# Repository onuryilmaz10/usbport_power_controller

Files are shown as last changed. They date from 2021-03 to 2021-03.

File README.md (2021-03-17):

# usbport_power_controller
An arduino based product UPC allows you to manage the connection of your computer between usb powered device. You can control it remotely with serial communication software running on your system. 
Designed by Onur Yilmaz and Yusuf Arabaci. 

Contact mail: onr.yilmaz10@gmail.com

# Connection 
Detect CH340 in ComPorts list.
Baud Rate is 9600. After serial communication setup, connects if you send "C" (connect), disconnects if you send "D" (disconnect).

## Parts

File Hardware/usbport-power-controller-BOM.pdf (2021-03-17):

Qty | Designation | Package | Designator
6 | 22pF | C1206 | C1,C2,C11,C12,C18,C19
7 | 100nF | C1206 | C3,C5,C6,C13,C15,C16,C17
3 | 10uF | C1206 | C4,C7,C9
3 | 100uF | C1206 | C8,C10,C20
1 | 40V/1A Diode | DO214AC(SMA) | D1
1 | Green Red | LED-1206 | D2
1 | Connector USB B 90C | Female | J1
1 | Power Jack | 2.1x5x5mm | J2
1 | Connector USB 2.0 A H | Female | J3
1 | Pin Header | 6x1 | J4
1 | Pin Header(Power Jumper) | 2x1 | J5
1 | TX2-5V Relay | THT DPDT 2FORMC | K1
1 | BC817 | SOT23-BEC | Q1
2 | 12.000MHz Crystal | HC-49UP | Y1,Y2
1 | 16.000MHz Crystal | HC-49UP | Y3
1 | 2.7k Ohm | R1206 | R1
3 | 100k Ohm | R1206 | R2,R3,R5
1 | 47k Ohm | R1206 | R4
1 | 330 Ohm | R1206 | R6
1 | Fe1.1S 4P Hub Controller 2.0 | SSOP28 | U1
1 | CH340G | SOIC16 | U2
1 | IC MCU 8BIT 32KB FLASH | TQFP-32 | Atmega328P-AU

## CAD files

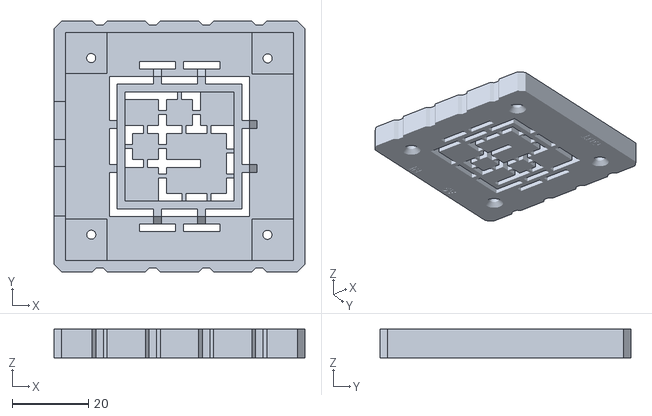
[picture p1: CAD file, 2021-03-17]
3dPrint/cap.stl
66.0 x 66.0 x 7.50

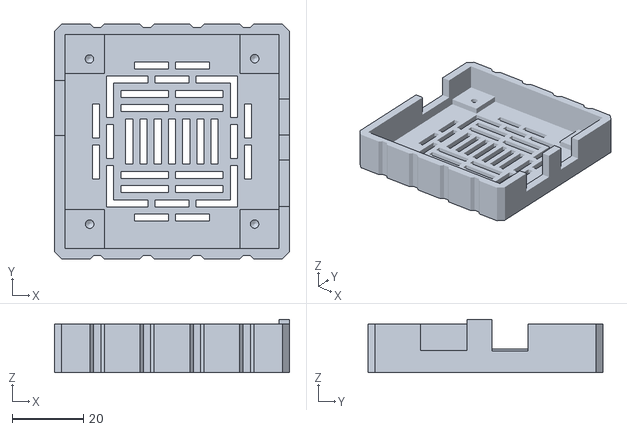
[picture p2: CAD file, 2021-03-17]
3dPrint/box.stl
66.0 x 66.0 x 15.0

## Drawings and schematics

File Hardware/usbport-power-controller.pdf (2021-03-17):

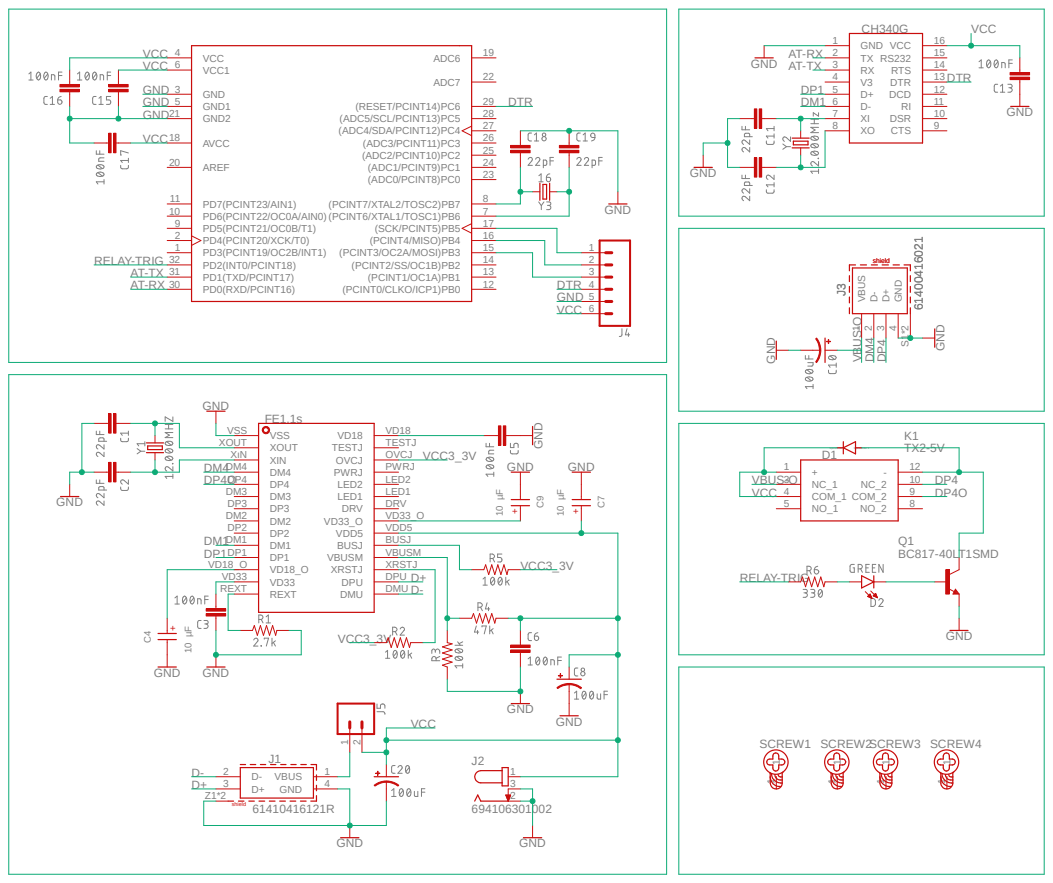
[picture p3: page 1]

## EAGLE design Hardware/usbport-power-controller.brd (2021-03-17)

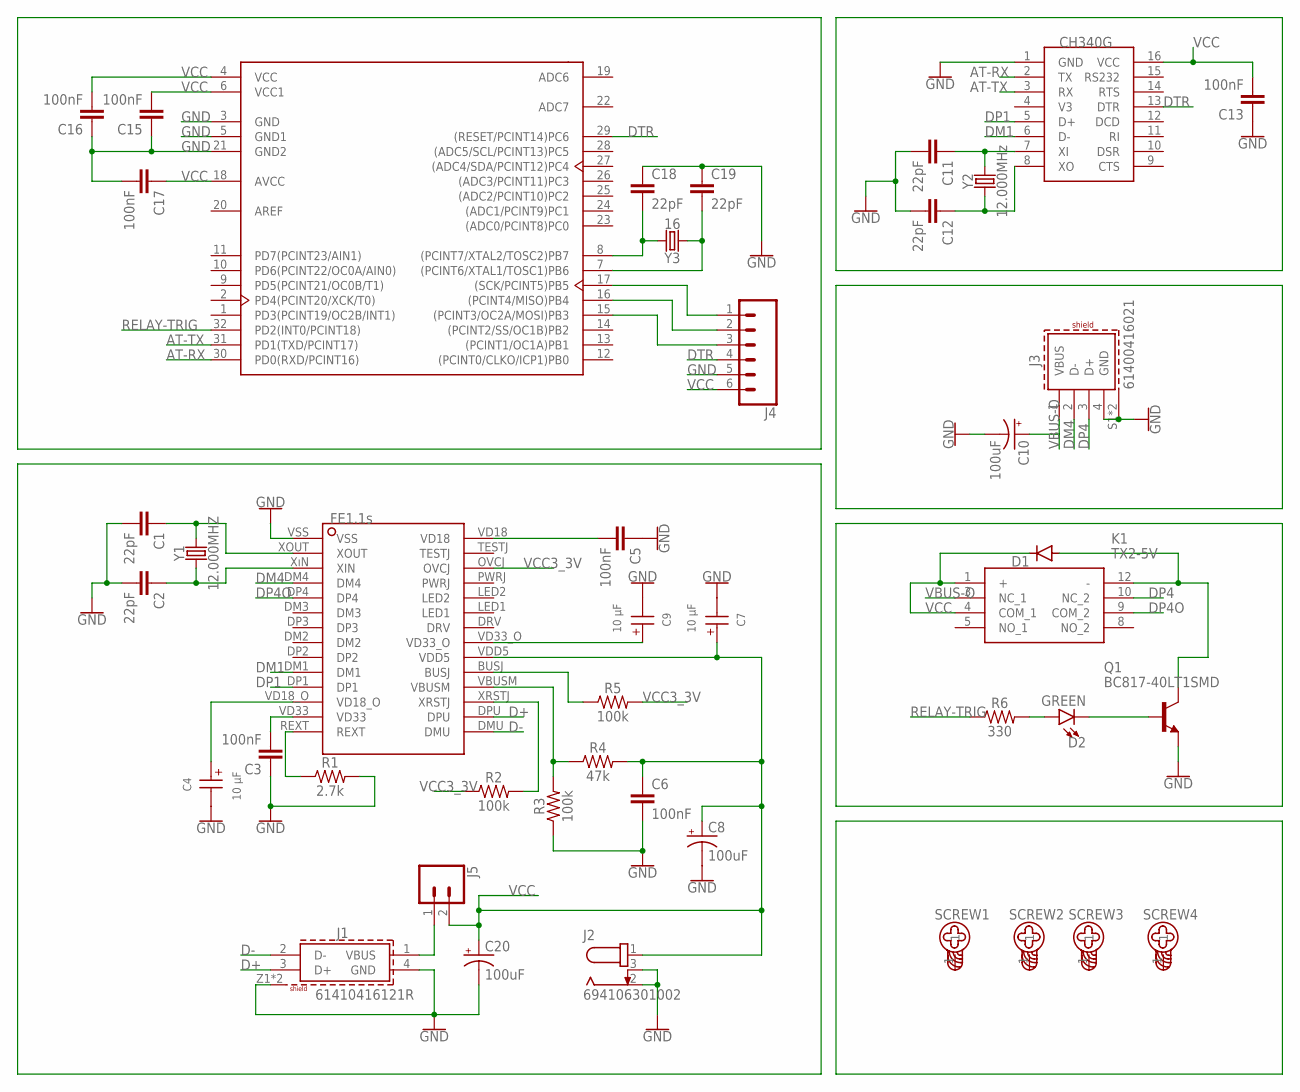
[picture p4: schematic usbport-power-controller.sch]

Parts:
ATMEGA328P-AU: ATMEGA328P-AU; TQFP-32
C1, C2, C11, C12, C18, C19: 22pF; 1206
C3, C5, C6, C13, C15, C16, C17: 100nF; 1206
C4, C7, C9: 10 µF; WCAP-ASLI_4X5.5(DXL)
C8, C10, C20: 100uF; PANASONIC_D
D1: DIODE-DO-214AC; DO-214AC
D2: GREEN; LED-1206
J1: 61410416121R
J2: 694106301002
J3: 61400416021
J4: CONN_06NO_SILK_FEMALE_PTH; 1X06_NO_SILK
J5: CONN_02; 1X02
K1: TX2-5V; TX2-24V
Q1: BC817-40LT1SMD; SOT23-BEC
R1: 2.7k; 1206
R2, R3, R5: 100k; 1206
R4: 47k; 1206
R6: 330; 1206
SCREW1, SCREW2, SCREW3, SCREW4: 4946
U$1: FE1.1S
U$2: CH340G; SOIC16
Y1: 12.000MHZ; HC49UP
Y2: 12.000MHz; HC49UP
Y3: 16; HC49UP

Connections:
AREF: ATMEGA328P-AU.20 (AREF)
AT-RX: ATMEGA328P-AU.30 (PD0(RXD/PCINT16)), U$2.2 (TX)
AT-TX: ATMEGA328P-AU.31 (PD1(TXD/PCINT17)), U$2.3 (RX)
D+: J1.3 (D+), U$1.DPU
D-: J1.2 (D-), U$1.DMU
DM1: U$1.DM1, U$2.6 (D-)
DM4: J3.2 (D-), U$1.DM4
DP1: U$1.DP1, U$2.5 (D+)
DP4: J3.3 (D+), K1.10 (NC_2)
DP4O: K1.9 (COM_2), U$1.DP4
DTR: ATMEGA328P-AU.29 ((RESET/PCINT14)PC6), J4.4, U$2.13 (DTR)
GND: ATMEGA328P-AU.3 (GND), ATMEGA328P-AU.5 (GND1), ATMEGA328P-AU.21 (GND2), C1.2, C2.2, C3.1, C4.2 (-), C5.1, C6.2, C7.2 (-), C8.-, C9.2 (-), C10.-, C11.2, C12.2, C13.1, C15.1, C16.1, C17.2, C18.1, C19.1, C20.-, J1.4 (GND), J1.Z1 (SHIELD), J1.Z2 (SHIELD), J2.2, J2.3, J3.4 (GND), J3.S1 (SHIELD), J3.S2 (SHIELD), J4.5, Q1.E, R1.2, R3.1, U$1.VSS, U$2.1 (GND)
unnamed: C2.1, U$1.XıN (XIN), Y1.1
unnamed: R2.2, U$1.XRSTJ
unnamed: R3.2, R4.1, U$1.VBUSM
unnamed: R1.1, U$1.REXT
unnamed: C1.1, U$1.XOUT, Y1.2
unnamed: C3.2, U$1.VD33
unnamed: R5.1, U$1.BUSJ
unnamed: D1.A, K1.12 (-), Q1.C
unnamed: C12.1, U$2.8 (XO), Y2.1
unnamed: C4.1 (+), U$1.VD18_O
unnamed: C11.1, U$2.7 (XI), Y2.2
unnamed: D2.C, Q1.B
unnamed: D2.A, R6.2
unnamed: ATMEGA328P-AU.8 ((PCINT7/XTAL2/TOSC2)PB7), C18.2, Y3.2
unnamed: ATMEGA328P-AU.17 ((SCK/PCINT5)PB5), J4.1
unnamed: ATMEGA328P-AU.7 ((PCINT6/XTAL1/TOSC1)PB6), C19.2, Y3.1
unnamed: ATMEGA328P-AU.16 ((PCINT4/MISO)PB4), J4.2
unnamed: ATMEGA328P-AU.15 ((PCINT3/OC2A/MOSI)PB3), J4.3
unnamed: J1.1 (VBUS), J5.1
unnamed: C5.2, U$1.VD18
RELAY-TRIG: ATMEGA328P-AU.32 (PD2(INT0/PCINT18)), R6.1
VBUS-O: C10.+, J3.1 (VBUS), K1.3 (NC_1)
VCC: ATMEGA328P-AU.4 (VCC), ATMEGA328P-AU.6 (VCC1), ATMEGA328P-AU.18 (AVCC), C6.1, C7.1 (+), C8.+, C13.2, C15.2, C16.2, C17.1, C20.+, D1.C, J2.1, J4.6, J5.2, K1.1 (+), K1.4 (COM_1), R4.2, U$1.VDD5, U$2.16 (VCC)
VCC3_3V: C9.1 (+), R2.1, R5.2, U$1.OVCJ, U$1.VD33_O

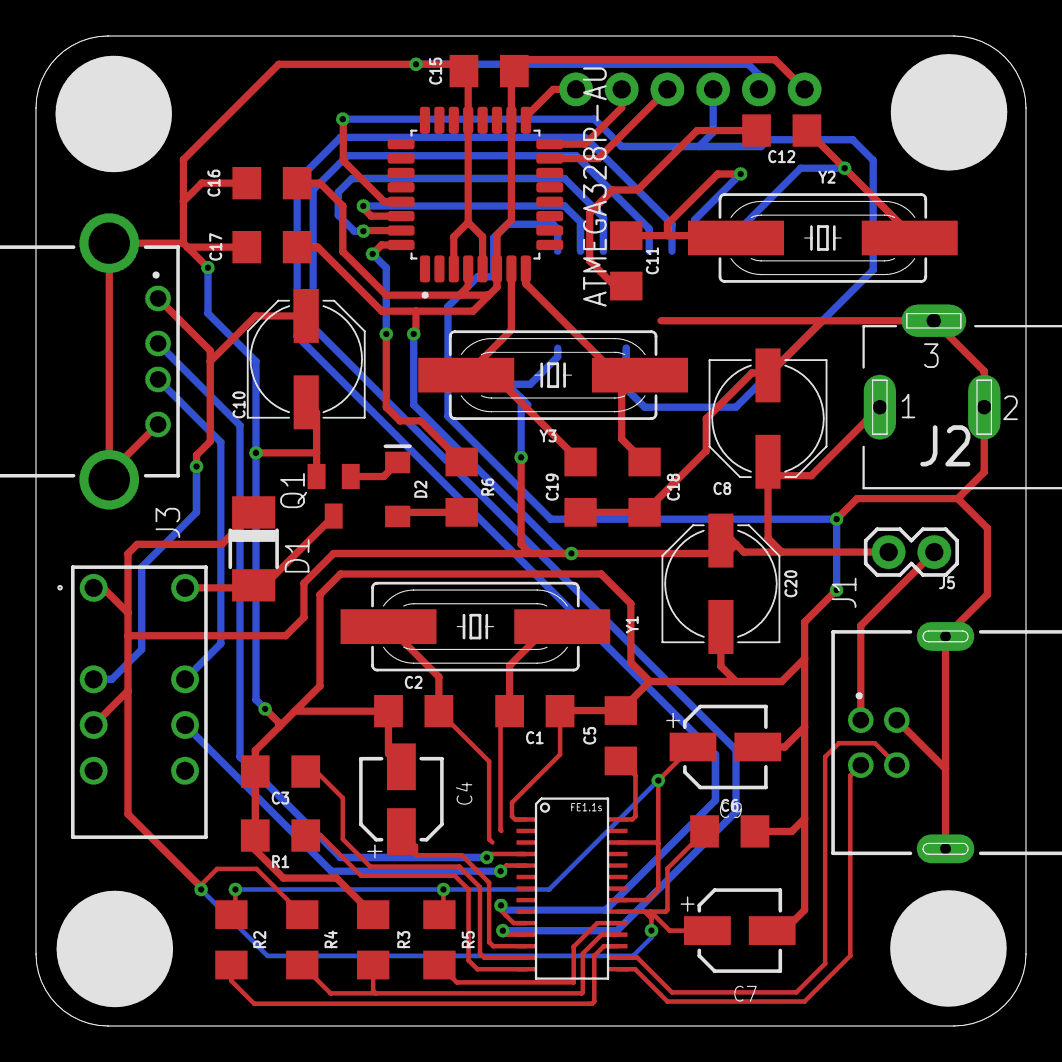
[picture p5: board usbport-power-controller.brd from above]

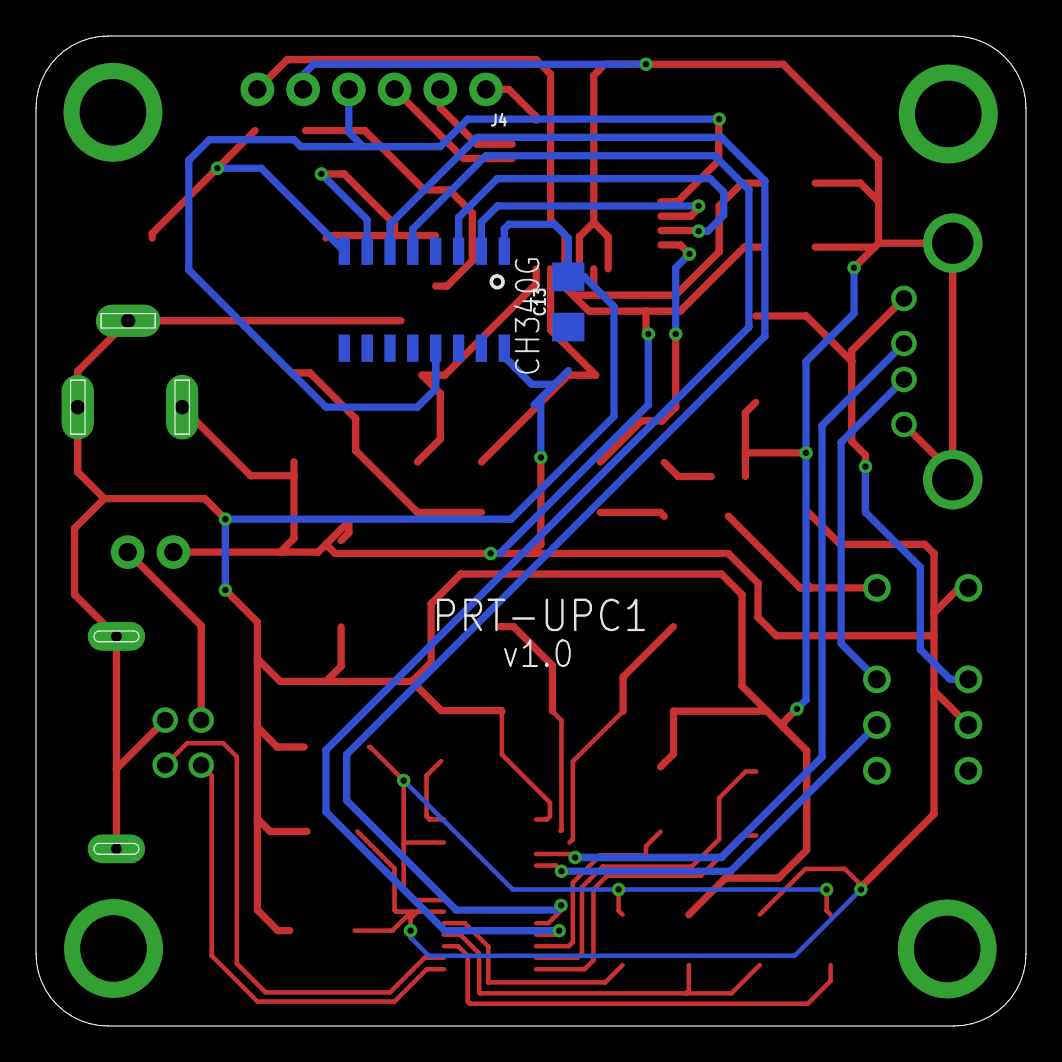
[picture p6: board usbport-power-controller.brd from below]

Board: 2 copper layers, 55.0 x 55.0 mm, 44 parts (3 on the bottom side), 35 nets.

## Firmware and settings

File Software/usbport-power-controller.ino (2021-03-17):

//0 low - port is connected
//1 high - port is disconnected

#include <EEPROM.h>

int data;

void setup()
{
  Serial.begin(9600);
  pinMode(2, OUTPUT);
}

void loop()
{
  int address = 10;

  data = EEPROM.read(address);

  if (data == 0) {
    digitalWrite(2, LOW);
  }
  else if (data == 1) {
    digitalWrite(2, HIGH);
  }
  else {
    EEPROM.write(address, 0);
  }


  if (Serial.available())
  {
    char data = Serial.read();
    switch (data)
    {
      case 'C':
        EEPROM.write(address, 0);
        delay(10);
        Serial.println("Opened");
        break;
      case 'D':
        EEPROM.write(address, 1);
        delay(10);
        Serial.println("Closed");
        break;
    }
  }

}

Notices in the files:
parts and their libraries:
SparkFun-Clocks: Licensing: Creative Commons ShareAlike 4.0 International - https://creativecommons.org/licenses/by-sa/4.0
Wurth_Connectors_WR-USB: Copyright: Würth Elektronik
